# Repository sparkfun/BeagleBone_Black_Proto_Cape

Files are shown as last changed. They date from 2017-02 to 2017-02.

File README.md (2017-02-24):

BeagleBone Black Proto Cape
===========================

[BeagleBone Black Proto Cape
*BeagleBone Black Proto Cape (DEV-12774)*](https://www.sparkfun.com/products/12774)
 
 A prototyping cape designed for the BeagleBone Black. It has blank EEPROM for pin configuration data and
 two red LEDs for debugging. 

Repository Contents
-------------------
* **/Hardware** - All Eagle design files (.brd, .sch, .STL)
* **/Production** - Test bed files and production panel files

Version History
---------------
* [V_1.0.0](https://github.com/sparkfun/BeagleBone_Black_Proto_Cape/tree/V_1.0.0) - Public release
* [V_1.0.1](https://github.com/sparkfun/BeagleBone_Black_Proto_Cape/tree/V_1.0.1) - Updated jumper packages to DFM standard (Increased aperture).

License Information
-------------------
The hardware is released under [Creative Commons ShareAlike 4.0 International](https://creativecommons.org/licenses/by-sa/4.0/).
The code is beerware; if you see me (or any other SparkFun employee) at the local, and you've found our code helpful, please buy us a round!

Distributed as-is; no warranty is given.

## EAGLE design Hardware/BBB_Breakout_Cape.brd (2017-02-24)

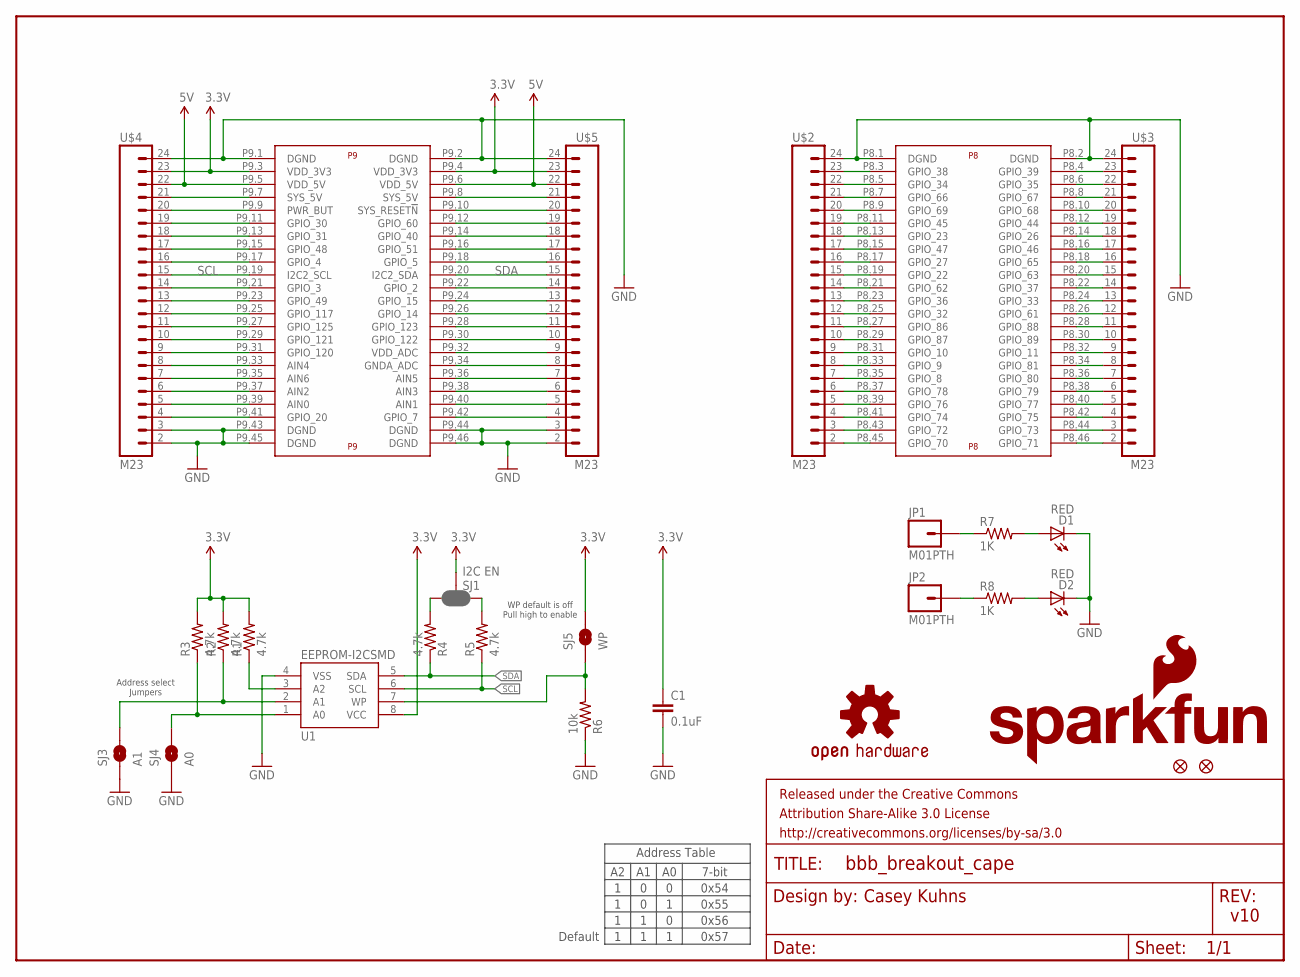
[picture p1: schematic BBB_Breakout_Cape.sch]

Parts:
C1: 0.1uF; 0603-CAP
D1, D2: RED; LED-0603
FID1, FID2: FIDUCIAL1X2; FIDUCIAL-1X2
FRAME1: FRAME-LETTER; CREATIVE_COMMONS
JP1, JP2: M01PTH; 1X01
LOGO2: OSHW-LOGOS; OSHW-LOGO-S
LOGO3: SFE_LOGO_NAME_FLAME.1_INCH; SFE_LOGO_NAME_FLAME_.1
R1, R2, R3, R4, R5: 4.7k; 0603@1
R6: 10k; 0603-RES
R7, R8: 1K; 0603-RES
SJ1: I2C EN; SMT-JUMPER_3_2-NC_PASTE_SILK
SJ3: A1; SMT-JUMPER_2_NO_SILK
SJ4: A0; SMT-JUMPER_2_NO_SILK
SJ5: WP; SMT-JUMPER_2_NO_SILK
U1: EEPROM-I2CSMD; SO08
U$1: BEAGLE_BONE_BLACK_CAPE
U$2, U$3, U$4, U$5: M23; 1X23

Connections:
3.3V: C1.1, R1.2, R2.2, R3.2, SJ1.2, SJ5.2, U1.8 (VCC), U$1.P9.3 (VDD_3V3), U$1.P9.4 (VDD_3V3), U$4.23, U$5.23
5V: U$1.P9.5 (VDD_5V), U$1.P9.6 (VDD_5V), U$4.22, U$5.22
A0: R3.1, SJ4.2, U1.1 (A0)
A1: R2.1, SJ3.2, U1.2 (A1)
GND: C1.2, D1.C, D2.C, R6.1, SJ3.1, SJ4.1, U1.4 (VSS), U$1.P8.1 (DGND), U$1.P8.2 (DGND), U$1.P9.1 (DGND), U$1.P9.2 (DGND), U$1.P9.43 (DGND), U$1.P9.44 (DGND), U$1.P9.45 (DGND), U$1.P9.46 (DGND), U$2.24, U$3.24, U$4.2, U$4.3, U$4.24, U$5.2, U$5.3, U$5.24
unnamed: R6.2, SJ5.1, U1.7 (WP)
unnamed: U$1.P8.45 (GPIO_70), U$2.2
unnamed: D1.A, R7.2
unnamed: U$1.P8.43 (GPIO_72), U$2.3
unnamed: U$1.P8.41 (GPIO_74), U$2.4
unnamed: R1.1, U1.3 (A2)
unnamed: D2.A, R8.2
unnamed: JP1.1, R7.1
unnamed: U$1.P8.39 (GPIO_76), U$2.5
unnamed: R4.2, SJ1.3
unnamed: R5.2, SJ1.1
unnamed: U$1.P8.37 (GPIO_78), U$2.6
unnamed: U$1.P8.35 (GPIO_8), U$2.7
unnamed: U$1.P8.33 (GPIO_9), U$2.8
unnamed: U$1.P8.31 (GPIO_10), U$2.9
unnamed: U$1.P8.29 (GPIO_87), U$2.10
unnamed: U$1.P8.27 (GPIO_86), U$2.11
unnamed: U$1.P8.25 (GPIO_32), U$2.12
unnamed: U$1.P8.23 (GPIO_36), U$2.13
unnamed: U$1.P8.21 (GPIO_62), U$2.14
unnamed: U$1.P8.19 (GPIO_22), U$2.15
unnamed: U$1.P8.17 (GPIO_27), U$2.16
unnamed: U$1.P8.15 (GPIO_47), U$2.17
unnamed: U$1.P8.13 (GPIO_23), U$2.18
unnamed: U$1.P8.11 (GPIO_45), U$2.19
unnamed: U$1.P8.9 (GPIO_69), U$2.20
unnamed: U$1.P8.7 (GPIO_66), U$2.21
unnamed: U$1.P8.5 (GPIO_34), U$2.22
unnamed: U$1.P8.3 (GPIO_38), U$2.23
unnamed: JP2.1, R8.1
unnamed: U$1.P8.46 (GPIO_71), U$3.2
unnamed: U$1.P8.44 (GPIO_73), U$3.3
unnamed: U$1.P8.42 (GPIO_75), U$3.4
unnamed: U$1.P8.40 (GPIO_77), U$3.5
unnamed: U$1.P8.38 (GPIO_79), U$3.6
unnamed: U$1.P8.36 (GPIO_80), U$3.7
unnamed: U$1.P8.34 (GPIO_81), U$3.8
unnamed: U$1.P8.32 (GPIO_11), U$3.9
unnamed: U$1.P8.30 (GPIO_89), U$3.10
unnamed: U$1.P8.28 (GPIO_88), U$3.11
unnamed: U$1.P8.26 (GPIO_61), U$3.12
unnamed: U$1.P8.24 (GPIO_33), U$3.13
unnamed: U$1.P8.22 (GPIO_37), U$3.14
unnamed: U$1.P8.20 (GPIO_63), U$3.15
unnamed: U$1.P8.18 (GPIO_65), U$3.16
unnamed: U$1.P8.16 (GPIO_46), U$3.17
unnamed: U$1.P8.14 (GPIO_26), U$3.18
unnamed: U$1.P8.12 (GPIO_44), U$3.19
unnamed: U$1.P8.10 (GPIO_68), U$3.20
unnamed: U$1.P8.8 (GPIO_67), U$3.21
unnamed: U$1.P8.6 (GPIO_35), U$3.22
unnamed: U$1.P8.4 (GPIO_39), U$3.23
unnamed: U$1.P9.42 (GPIO_7), U$5.4
unnamed: U$1.P9.40 (AIN1), U$5.5
unnamed: U$1.P9.38 (AIN3), U$5.6
unnamed: U$1.P9.36 (AIN5), U$5.7
unnamed: U$1.P9.34 (GNDA_ADC), U$5.8
unnamed: U$1.P9.32 (VDD_ADC), U$5.9
unnamed: U$1.P9.30 (GPIO_122), U$5.10
unnamed: U$1.P9.28 (GPIO_123), U$5.11
unnamed: U$1.P9.26 (GPIO_14), U$5.12
unnamed: U$1.P9.24 (GPIO_15), U$5.13
unnamed: U$1.P9.22 (GPIO_2), U$5.14
unnamed: U$1.P9.18 (GPIO_5), U$5.16
unnamed: U$1.P9.16 (GPIO_51), U$5.17
unnamed: U$1.P9.14 (GPIO_40), U$5.18
unnamed: U$1.P9.12 (GPIO_60), U$5.19
unnamed: U$1.P9.10 (SYS_RESET!N), U$5.20
unnamed: U$1.P9.8 (SYS_5V), U$5.21
unnamed: U$1.P9.41 (GPIO_20), U$4.4
unnamed: U$1.P9.39 (AIN0), U$4.5
unnamed: U$1.P9.37 (AIN2), U$4.6
unnamed: U$1.P9.35 (AIN6), U$4.7
unnamed: U$1.P9.33 (AIN4), U$4.8
unnamed: U$1.P9.31 (GPIO_120), U$4.9
unnamed: U$1.P9.29 (GPIO_121), U$4.10
unnamed: U$1.P9.27 (GPIO_125), U$4.11
unnamed: U$1.P9.25 (GPIO_117), U$4.12
unnamed: U$1.P9.23 (GPIO_49), U$4.13
unnamed: U$1.P9.21 (GPIO_3), U$4.14
unnamed: U$1.P9.17 (GPIO_4), U$4.16
unnamed: U$1.P9.15 (GPIO_48), U$4.17
unnamed: U$1.P9.13 (GPIO_31), U$4.18
unnamed: U$1.P9.11 (GPIO_30), U$4.19
unnamed: U$1.P9.9 (PWR_BUT), U$4.20
unnamed: U$1.P9.7 (SYS_5V), U$4.21
SCL: R5.1, U1.6 (SCL), U$1.P9.19 (I2C2_SCL), U$4.15
SDA: R4.1, U1.5 (SDA), U$1.P9.20 (I2C2_SDA), U$5.15

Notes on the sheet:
Address Table
Default
7-bit
0x54
0x56
0x55
0x57
Casey Kuhns
v10
WP default is off Pull high to enable
Address select Jumpers

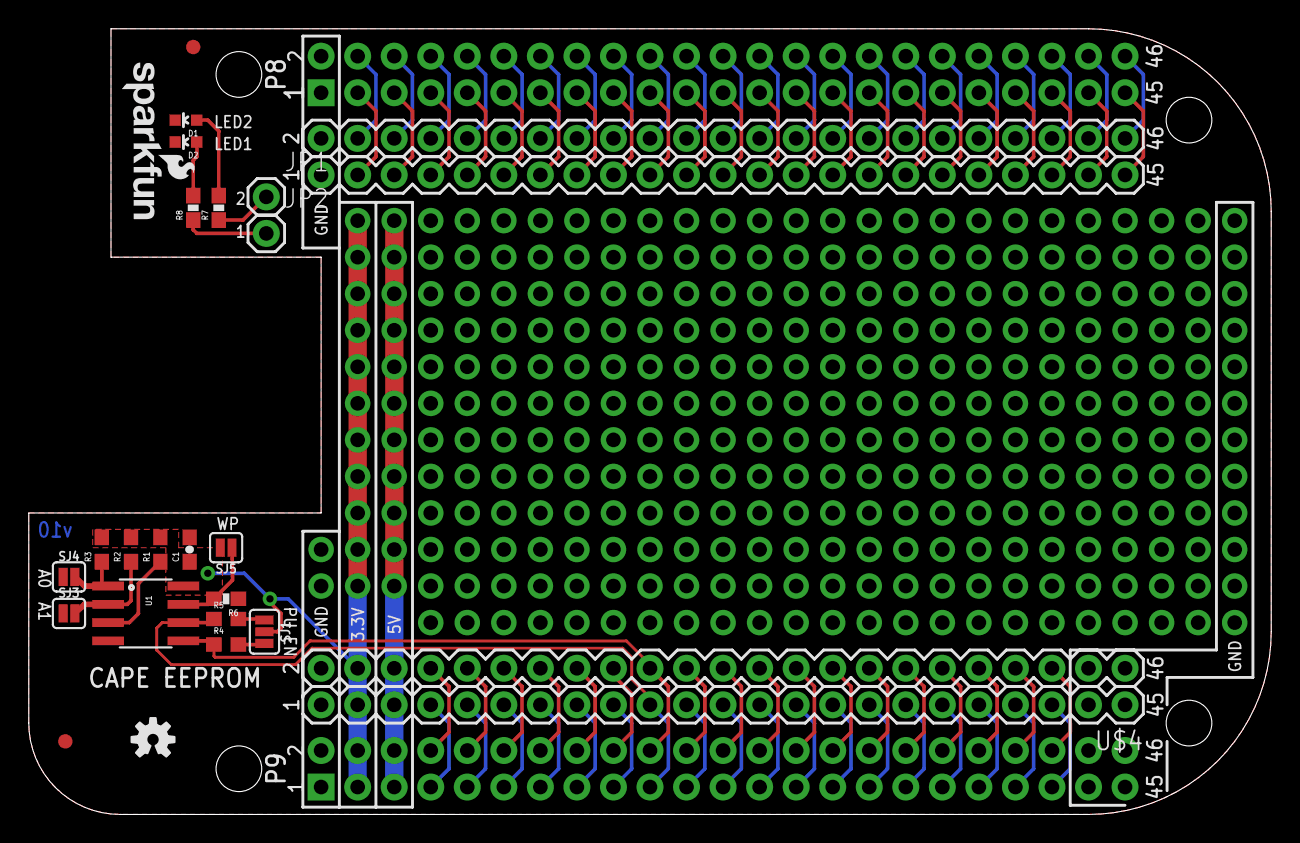
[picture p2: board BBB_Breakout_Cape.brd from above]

Board: 2 copper layers, 86.4 x 54.6 mm, 29 parts (1 on the bottom side), 93 nets.

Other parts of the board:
U$6: SFE_LOGO_NAME_FLAME_.1

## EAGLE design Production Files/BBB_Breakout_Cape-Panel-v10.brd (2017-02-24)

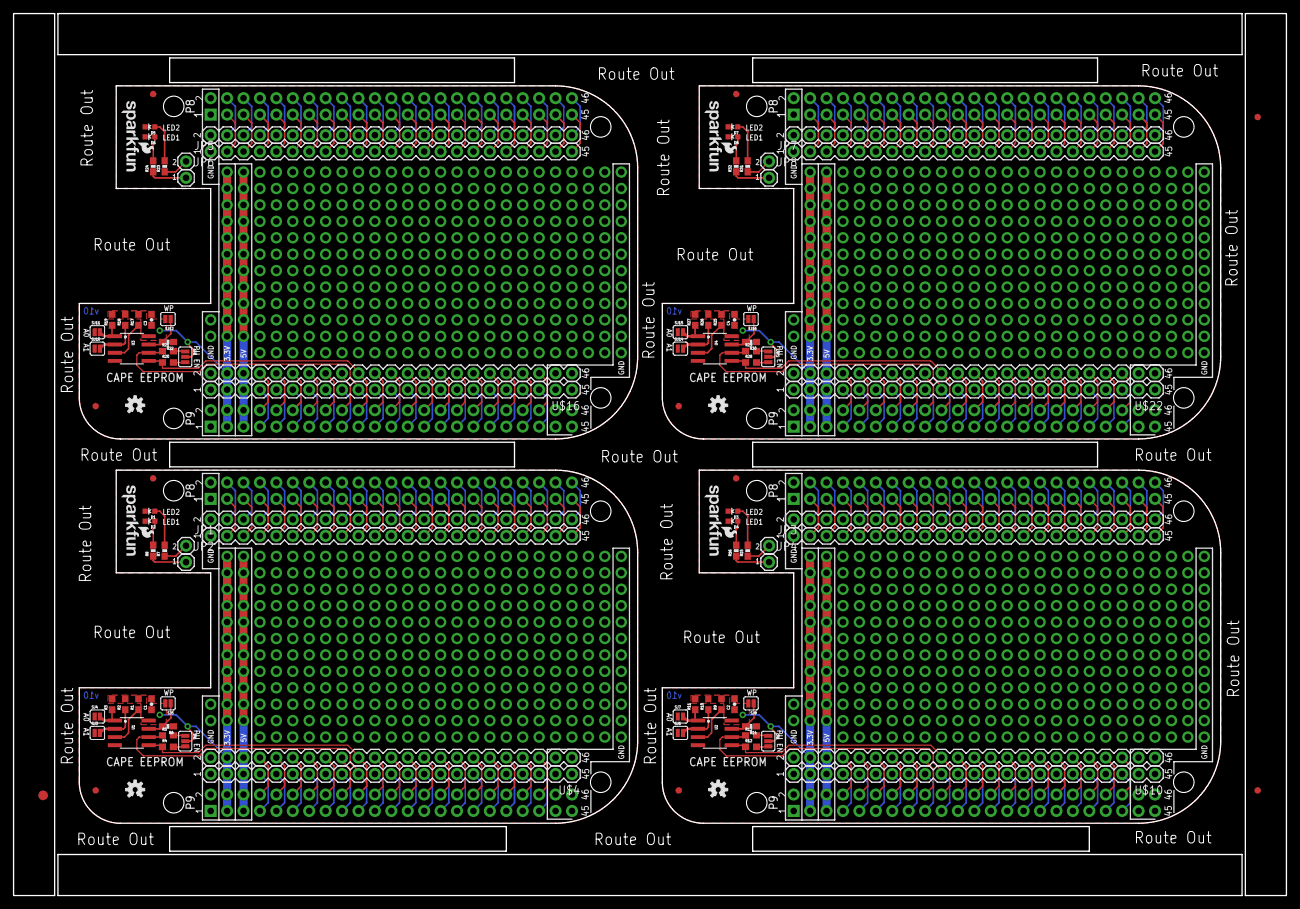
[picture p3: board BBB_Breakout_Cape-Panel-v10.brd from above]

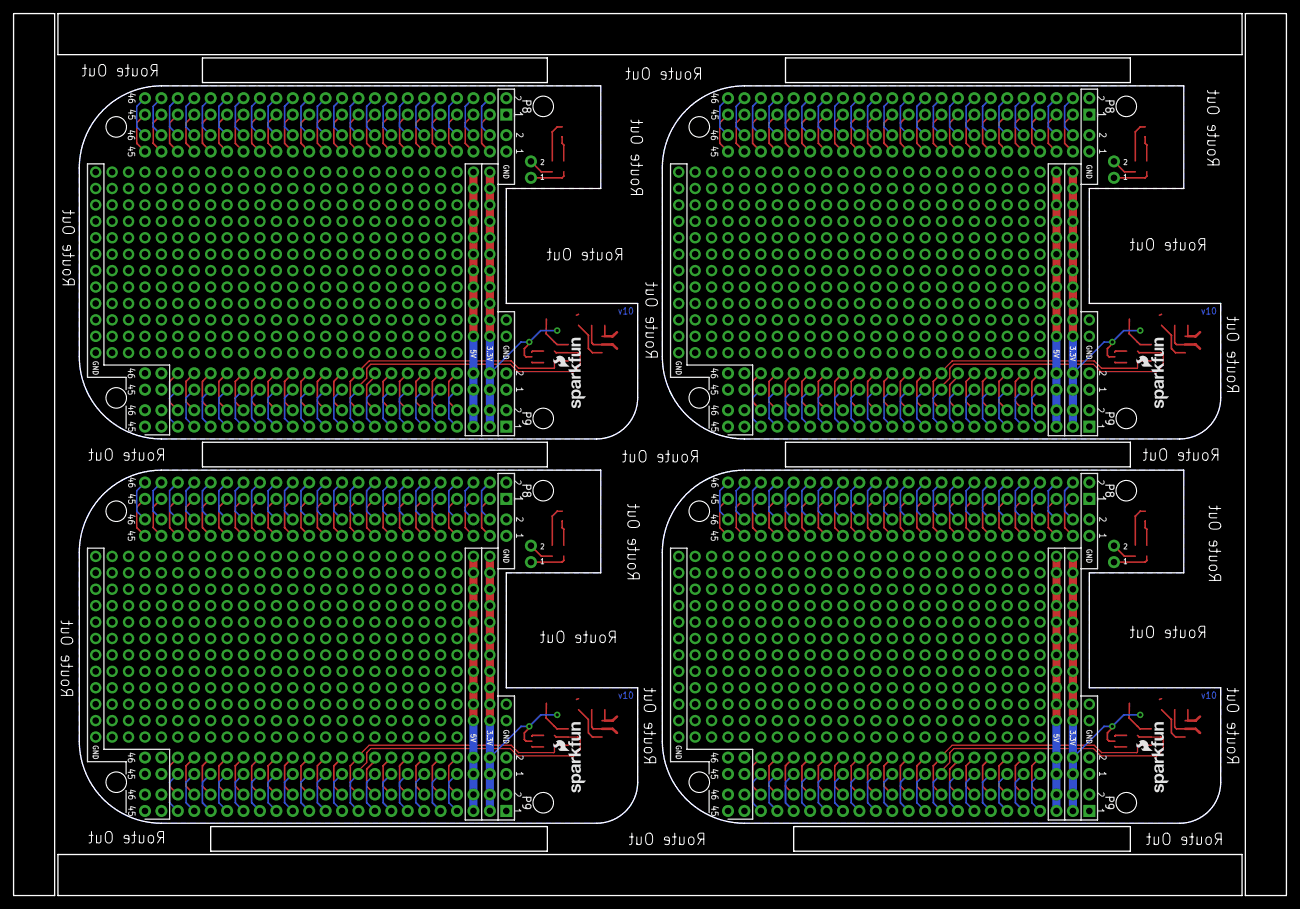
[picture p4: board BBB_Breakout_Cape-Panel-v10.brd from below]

Board: 2 copper layers, 196.8 x 136.4 mm, 115 parts (4 on the bottom side), 372 nets.

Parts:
C1, C2, C3, C4: 0.1uF; 0603-CAP
D1, D2, D3, D4, D5, D6, D7, D8: RED; LED-0603
E$1: FIDUCIAL-1.5X3
E$3, E$4: FIDUCIAL-1X2
FID1, FID2, FID3, FID4, FID5, FID6, FID7, FID8: FIDUCIAL1X2; FIDUCIAL-1X2
JP1, JP2, JP3, JP4, JP5, JP6, JP7, JP8: M01PTH; 1X01
LOGO1, LOGO3, LOGO5, LOGO7: SFE_LOGO_NAME_FLAME.1_INCH; SFE_LOGO_NAME_FLAME_.1
LOGO2, LOGO4, LOGO6, LOGO8: OSHW-LOGOS; OSHW-LOGO-S
R1, R2, R3, R4, R5, R9, R10, R11, R12, R13, R17, R18, R19, R20, R21, R25, R26, R27, R28, R29: 4.7k; 0603
R6, R14, R22, R30: 10k; 0603-RES
R7, R8, R15, R16, R23, R24, R31, R32: 1K; 0603-RES
SJ1, SJ2, SJ9, SJ13: I2C EN; SMT-JUMPER_3_2-NC_PASTE_SILK
SJ3, SJ6, SJ10, SJ14: A1; SMT-JUMPER_2_NO_SILK
SJ4, SJ7, SJ11, SJ15: A0; SMT-JUMPER_2_NO_SILK
SJ5, SJ8, SJ12, SJ16: WP; SMT-JUMPER_2_NO_SILK
U1, U2, U3, U4: EEPROM-I2CSMD; SO08
U$1, U$7, U$13, U$19: BEAGLE_BONE_BLACK_CAPE
U$2, U$3, U$4, U$5, U$8, U$9, U$10, U$11, U$14, U$15, U$16, U$17, U$20, U$21, U$22, U$23: M23; 1X23
U$6, U$12, U$18, U$24: SFE_LOGO_NAME_FLAME_.1

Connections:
3.3V: C1.1, R1.2, R2.2, R3.2, SJ1.2, SJ5.2, U1.8, U$1.P9.3, U$1.P9.4, U$4.23, U$5.23
3.3V1: C2.1, R9.2, R10.2, R11.2, SJ2.2, SJ8.2, U2.8, U$7.P9.3, U$7.P9.4, U$10.23, U$11.23
3.3V2: C3.1, R17.2, R18.2, R19.2, SJ9.2, SJ12.2, U3.8, U$13.P9.3, U$13.P9.4, U$16.23, U$17.23
3.3V3: C4.1, R25.2, R26.2, R27.2, SJ13.2, SJ16.2, U4.8, U$19.P9.3, U$19.P9.4, U$22.23, U$23.23
5V: U$1.P9.5, U$1.P9.6, U$4.22, U$5.22
5V1: U$7.P9.5, U$7.P9.6, U$10.22, U$11.22
5V2: U$13.P9.5, U$13.P9.6, U$16.22, U$17.22
5V3: U$19.P9.5, U$19.P9.6, U$22.22, U$23.22
A0: R3.1, SJ4.2, U1.1
A1: R2.1, SJ3.2, U1.2
A2: R10.1, SJ6.2, U2.2
A3: R11.1, SJ7.2, U2.1
A4: R18.1, SJ10.2, U3.2
A5: R19.1, SJ11.2, U3.1
A6: R26.1, SJ14.2, U4.2
A7: R27.1, SJ15.2, U4.1
GND: C1.2, D1.C, D2.C, R6.1, SJ3.1, SJ4.1, U1.4, U$1.P8.1, U$1.P8.2, U$1.P9.1, U$1.P9.2, U$1.P9.43, U$1.P9.44, U$1.P9.45, U$1.P9.46, U$2.24, U$3.24, U$4.2, U$4.3, U$4.24, U$5.2, U$5.3, U$5.24
GND1: C2.2, D3.C, D4.C, R14.1, SJ6.1, SJ7.1, U2.4, U$7.P8.1, U$7.P8.2, U$7.P9.1, U$7.P9.2, U$7.P9.43, U$7.P9.44, U$7.P9.45, U$7.P9.46, U$8.24, U$9.24, U$10.2, U$10.3, U$10.24, U$11.2, U$11.3, U$11.24
GND2: C3.2, D5.C, D6.C, R22.1, SJ10.1, SJ11.1, U3.4, U$13.P8.1, U$13.P8.2, U$13.P9.1, U$13.P9.2, U$13.P9.43, U$13.P9.44, U$13.P9.45, U$13.P9.46, U$14.24, U$15.24, U$16.2, U$16.3, U$16.24, U$17.2, U$17.3, U$17.24
GND3: C4.2, D7.C, D8.C, R30.1, SJ14.1, SJ15.1, U4.4, U$19.P8.1, U$19.P8.2, U$19.P9.1, U$19.P9.2, U$19.P9.43, U$19.P9.44, U$19.P9.45, U$19.P9.46, U$20.24, U$21.24, U$22.2, U$22.3, U$22.24, U$23.2, U$23.3, U$23.24
unnamed: R6.2, SJ5.1, U1.7
unnamed: U$1.P8.45, U$2.2
unnamed: D1.A, R7.2
unnamed: U$1.P8.43, U$2.3
unnamed: U$1.P8.41, U$2.4
unnamed: R1.1, U1.3
unnamed: D2.A, R8.2
unnamed: JP1.1, R7.1
unnamed: U$1.P8.39, U$2.5
unnamed: R4.2, SJ1.3
unnamed: R5.2, SJ1.1
unnamed: U$1.P8.37, U$2.6
unnamed: U$1.P8.35, U$2.7
unnamed: U$1.P8.33, U$2.8
unnamed: U$1.P8.31, U$2.9
unnamed: U$1.P8.29, U$2.10
unnamed: U$1.P8.27, U$2.11
unnamed: U$1.P8.25, U$2.12
unnamed: U$1.P8.23, U$2.13
unnamed: U$1.P8.21, U$2.14
unnamed: U$1.P8.19, U$2.15
unnamed: U$1.P8.17, U$2.16
unnamed: U$1.P8.15, U$2.17
unnamed: U$1.P8.13, U$2.18
unnamed: U$1.P8.11, U$2.19
unnamed: U$1.P8.9, U$2.20
unnamed: U$1.P8.7, U$2.21
unnamed: U$1.P8.5, U$2.22
unnamed: U$1.P8.3, U$2.23
unnamed: JP2.1, R8.1
unnamed: U$1.P8.46, U$3.2
unnamed: U$1.P8.44, U$3.3
unnamed: U$1.P8.42, U$3.4
unnamed: U$1.P8.40, U$3.5
unnamed: U$1.P8.38, U$3.6
unnamed: U$1.P8.36, U$3.7
unnamed: U$1.P8.34, U$3.8
unnamed: U$1.P8.32, U$3.9
unnamed: U$1.P8.30, U$3.10
unnamed: U$1.P8.28, U$3.11
unnamed: U$1.P8.26, U$3.12
unnamed: U$1.P8.24, U$3.13
unnamed: U$1.P8.22, U$3.14
unnamed: U$1.P8.20, U$3.15
unnamed: U$1.P8.18, U$3.16
unnamed: U$1.P8.16, U$3.17
unnamed: U$1.P8.14, U$3.18
unnamed: U$1.P8.12, U$3.19
unnamed: U$1.P8.10, U$3.20
unnamed: U$1.P8.8, U$3.21
unnamed: U$1.P8.6, U$3.22
unnamed: U$1.P8.4, U$3.23
unnamed: R9.1, U2.3
unnamed: R12.2, SJ2.3
unnamed: R13.2, SJ2.1
unnamed: U$1.P9.42, U$5.4
unnamed: U$1.P9.40, U$5.5
unnamed: U$1.P9.38, U$5.6
unnamed: U$1.P9.36, U$5.7
unnamed: U$1.P9.34, U$5.8
unnamed: U$1.P9.32, U$5.9
unnamed: U$1.P9.30, U$5.10
unnamed: U$1.P9.28, U$5.11
unnamed: U$1.P9.26, U$5.12
unnamed: U$1.P9.24, U$5.13
unnamed: U$1.P9.22, U$5.14
unnamed: U$7.P8.45, U$8.2
unnamed: U$1.P9.18, U$5.16
unnamed: U$1.P9.16, U$5.17
unnamed: U$1.P9.14, U$5.18
unnamed: U$1.P9.12, U$5.19
unnamed: U$1.P9.10, U$5.20
unnamed: U$1.P9.8, U$5.21
unnamed: U$7.P8.43, U$8.3
unnamed: U$7.P8.41, U$8.4
unnamed: U$7.P8.39, U$8.5
unnamed: U$7.P8.37, U$8.6
unnamed: U$7.P8.35, U$8.7
unnamed: U$1.P9.41, U$4.4
unnamed: U$1.P9.39, U$4.5
unnamed: U$1.P9.37, U$4.6
unnamed: U$1.P9.35, U$4.7
unnamed: U$1.P9.33, U$4.8
unnamed: U$1.P9.31, U$4.9
unnamed: U$1.P9.29, U$4.10
unnamed: U$1.P9.27, U$4.11
unnamed: U$1.P9.25, U$4.12
unnamed: U$1.P9.23, U$4.13
unnamed: U$1.P9.21, U$4.14
unnamed: U$7.P8.33, U$8.8
unnamed: U$1.P9.17, U$4.16
unnamed: U$1.P9.15, U$4.17
unnamed: U$1.P9.13, U$4.18
unnamed: U$1.P9.11, U$4.19
unnamed: U$1.P9.9, U$4.20
unnamed: U$1.P9.7, U$4.21
unnamed: U$7.P8.31, U$8.9
unnamed: U$7.P8.29, U$8.10
unnamed: U$7.P8.27, U$8.11
unnamed: U$7.P8.25, U$8.12
unnamed: U$7.P8.23, U$8.13
unnamed: U$7.P8.21, U$8.14
unnamed: U$7.P8.19, U$8.15
unnamed: U$7.P8.17, U$8.16
unnamed: U$7.P8.15, U$8.17
unnamed: U$7.P8.13, U$8.18
unnamed: U$7.P8.11, U$8.19
unnamed: U$7.P8.9, U$8.20
unnamed: U$7.P8.7, U$8.21
unnamed: U$7.P8.5, U$8.22
unnamed: U$7.P8.3, U$8.23
unnamed: U$7.P8.46, U$9.2
unnamed: U$7.P8.44, U$9.3
unnamed: U$7.P8.42, U$9.4
unnamed: U$7.P8.40, U$9.5
unnamed: U$7.P8.38, U$9.6
unnamed: U$7.P8.36, U$9.7
unnamed: U$7.P8.34, U$9.8
unnamed: U$7.P8.32, U$9.9
unnamed: U$7.P8.30, U$9.10
unnamed: U$7.P8.28, U$9.11
unnamed: U$7.P8.26, U$9.12
unnamed: U$7.P8.24, U$9.13
unnamed: U$7.P8.22, U$9.14
unnamed: U$7.P8.20, U$9.15
unnamed: U$7.P8.18, U$9.16
unnamed: U$7.P8.16, U$9.17
unnamed: U$7.P8.14, U$9.18
unnamed: U$7.P8.12, U$9.19
unnamed: U$7.P8.10, U$9.20
unnamed: U$7.P8.8, U$9.21
unnamed: U$7.P8.6, U$9.22
unnamed: U$7.P8.4, U$9.23
unnamed: U$7.P9.42, U$11.4
unnamed: U$7.P9.40, U$11.5
unnamed: U$7.P9.38, U$11.6
unnamed: U$7.P9.36, U$11.7
unnamed: U$7.P9.34, U$11.8
unnamed: U$7.P9.32, U$11.9
unnamed: U$7.P9.30, U$11.10
unnamed: U$7.P9.28, U$11.11
unnamed: U$7.P9.26, U$11.12
unnamed: U$7.P9.24, U$11.13
unnamed: U$7.P9.22, U$11.14
unnamed: U$7.P9.18, U$11.16
unnamed: U$7.P9.16, U$11.17
unnamed: U$7.P9.14, U$11.18
unnamed: U$7.P9.12, U$11.19
unnamed: U$7.P9.10, U$11.20
unnamed: U$7.P9.8, U$11.21
unnamed: U$7.P9.41, U$10.4
unnamed: U$7.P9.39, U$10.5
unnamed: U$7.P9.37, U$10.6
unnamed: U$7.P9.35, U$10.7
unnamed: U$7.P9.33, U$10.8
unnamed: U$7.P9.31, U$10.9
unnamed: U$7.P9.29, U$10.10
unnamed: U$7.P9.27, U$10.11
unnamed: U$7.P9.25, U$10.12
unnamed: U$7.P9.23, U$10.13
unnamed: U$7.P9.21, U$10.14
unnamed: U$7.P9.17, U$10.16
unnamed: U$7.P9.15, U$10.17
unnamed: U$7.P9.13, U$10.18
unnamed: U$7.P9.11, U$10.19
unnamed: U$7.P9.9, U$10.20
unnamed: U$7.P9.7, U$10.21
unnamed: R14.2, SJ8.1, U2.7
unnamed: D3.A, R15.2
unnamed: D4.A, R16.2
unnamed: JP3.1, R15.1
unnamed: JP4.1, R16.1
unnamed: R17.1, U3.3
unnamed: R20.2, SJ9.3
unnamed: R21.2, SJ9.1
unnamed: U$13.P8.45, U$14.2
unnamed: U$13.P8.43, U$14.3
unnamed: U$13.P8.41, U$14.4
unnamed: U$13.P8.39, U$14.5
unnamed: U$13.P8.37, U$14.6
unnamed: U$13.P8.35, U$14.7
unnamed: U$13.P8.33, U$14.8
unnamed: U$13.P8.31, U$14.9
unnamed: U$13.P8.29, U$14.10
unnamed: U$13.P8.27, U$14.11
unnamed: U$13.P8.25, U$14.12
unnamed: U$13.P8.23, U$14.13
unnamed: U$13.P8.21, U$14.14
unnamed: U$13.P8.19, U$14.15
unnamed: U$13.P8.17, U$14.16
unnamed: U$13.P8.15, U$14.17
unnamed: U$13.P8.13, U$14.18
unnamed: U$13.P8.11, U$14.19
unnamed: U$13.P8.9, U$14.20
unnamed: U$13.P8.7, U$14.21
unnamed: U$13.P8.5, U$14.22
unnamed: U$13.P8.3, U$14.23
unnamed: U$13.P8.46, U$15.2
unnamed: U$13.P8.44, U$15.3
unnamed: U$13.P8.42, U$15.4
unnamed: U$13.P8.40, U$15.5
unnamed: U$13.P8.38, U$15.6
unnamed: U$13.P8.36, U$15.7
unnamed: U$13.P8.34, U$15.8
unnamed: U$13.P8.32, U$15.9
unnamed: U$13.P8.30, U$15.10
unnamed: U$13.P8.28, U$15.11
unnamed: U$13.P8.26, U$15.12
unnamed: U$13.P8.24, U$15.13
unnamed: U$13.P8.22, U$15.14
unnamed: U$13.P8.20, U$15.15
unnamed: U$13.P8.18, U$15.16
unnamed: U$13.P8.16, U$15.17
unnamed: U$13.P8.14, U$15.18
unnamed: U$13.P8.12, U$15.19
unnamed: U$13.P8.10, U$15.20
unnamed: U$13.P8.8, U$15.21
unnamed: U$13.P8.6, U$15.22
unnamed: U$13.P8.4, U$15.23
unnamed: U$13.P9.42, U$17.4
unnamed: U$13.P9.40, U$17.5
unnamed: U$13.P9.38, U$17.6
unnamed: U$13.P9.36, U$17.7
unnamed: U$13.P9.34, U$17.8
unnamed: U$13.P9.32, U$17.9
unnamed: U$13.P9.30, U$17.10
unnamed: U$13.P9.28, U$17.11
unnamed: U$13.P9.26, U$17.12
unnamed: U$13.P9.24, U$17.13
unnamed: U$13.P9.22, U$17.14
unnamed: U$13.P9.18, U$17.16
unnamed: U$13.P9.16, U$17.17
unnamed: U$13.P9.14, U$17.18
unnamed: U$13.P9.12, U$17.19
unnamed: U$13.P9.10, U$17.20
unnamed: U$13.P9.8, U$17.21
unnamed: U$13.P9.41, U$16.4
unnamed: U$13.P9.39, U$16.5
unnamed: U$13.P9.37, U$16.6
unnamed: U$13.P9.35, U$16.7
unnamed: U$13.P9.33, U$16.8
unnamed: U$13.P9.31, U$16.9
unnamed: U$13.P9.29, U$16.10
unnamed: U$13.P9.27, U$16.11
unnamed: U$13.P9.25, U$16.12
unnamed: U$13.P9.23, U$16.13
unnamed: U$13.P9.21, U$16.14
unnamed: U$13.P9.17, U$16.16
unnamed: U$13.P9.15, U$16.17
unnamed: U$13.P9.13, U$16.18
unnamed: U$13.P9.11, U$16.19
unnamed: U$13.P9.9, U$16.20
unnamed: U$13.P9.7, U$16.21
unnamed: R22.2, SJ12.1, U3.7
unnamed: D5.A, R23.2
unnamed: D6.A, R24.2
unnamed: JP5.1, R23.1
unnamed: JP6.1, R24.1
unnamed: R25.1, U4.3
unnamed: R28.2, SJ13.3
unnamed: R29.2, SJ13.1
unnamed: U$19.P8.45, U$20.2
unnamed: U$19.P8.43, U$20.3
unnamed: U$19.P8.41, U$20.4
unnamed: U$19.P8.39, U$20.5
unnamed: U$19.P8.37, U$20.6
unnamed: U$19.P8.35, U$20.7
unnamed: U$19.P8.33, U$20.8
unnamed: U$19.P8.31, U$20.9
unnamed: U$19.P8.29, U$20.10
unnamed: U$19.P8.27, U$20.11
unnamed: U$19.P8.25, U$20.12
unnamed: U$19.P8.23, U$20.13
unnamed: U$19.P8.21, U$20.14
unnamed: U$19.P8.19, U$20.15
unnamed: U$19.P8.17, U$20.16
unnamed: U$19.P8.15, U$20.17
unnamed: U$19.P8.13, U$20.18
unnamed: U$19.P8.11, U$20.19
unnamed: U$19.P8.9, U$20.20
unnamed: U$19.P8.7, U$20.21
unnamed: U$19.P8.5, U$20.22
unnamed: U$19.P8.3, U$20.23
unnamed: U$19.P8.46, U$21.2
unnamed: U$19.P8.44, U$21.3
unnamed: U$19.P8.42, U$21.4
unnamed: U$19.P8.40, U$21.5
unnamed: U$19.P8.38, U$21.6
unnamed: U$19.P8.36, U$21.7
unnamed: U$19.P8.34, U$21.8
unnamed: U$19.P8.32, U$21.9
unnamed: U$19.P8.30, U$21.10
unnamed: U$19.P8.28, U$21.11
unnamed: U$19.P8.26, U$21.12
unnamed: U$19.P8.24, U$21.13
unnamed: U$19.P8.22, U$21.14
unnamed: U$19.P8.20, U$21.15
unnamed: U$19.P8.18, U$21.16
unnamed: U$19.P8.16, U$21.17
unnamed: U$19.P8.14, U$21.18
unnamed: U$19.P8.12, U$21.19
unnamed: U$19.P8.10, U$21.20
unnamed: U$19.P8.8, U$21.21
unnamed: U$19.P8.6, U$21.22
unnamed: U$19.P8.4, U$21.23
unnamed: U$19.P9.42, U$23.4
unnamed: U$19.P9.40, U$23.5
unnamed: U$19.P9.38, U$23.6
unnamed: U$19.P9.36, U$23.7
unnamed: U$19.P9.34, U$23.8
unnamed: U$19.P9.32, U$23.9
unnamed: U$19.P9.30, U$23.10
unnamed: U$19.P9.28, U$23.11
unnamed: U$19.P9.26, U$23.12
unnamed: U$19.P9.24, U$23.13
unnamed: U$19.P9.22, U$23.14
unnamed: U$19.P9.18, U$23.16
unnamed: U$19.P9.16, U$23.17
unnamed: U$19.P9.14, U$23.18
unnamed: U$19.P9.12, U$23.19
unnamed: U$19.P9.10, U$23.20
unnamed: U$19.P9.8, U$23.21
unnamed: U$19.P9.41, U$22.4
unnamed: U$19.P9.39, U$22.5
unnamed: U$19.P9.37, U$22.6
unnamed: U$19.P9.35, U$22.7
unnamed: U$19.P9.33, U$22.8
unnamed: U$19.P9.31, U$22.9
unnamed: U$19.P9.29, U$22.10
unnamed: U$19.P9.27, U$22.11
unnamed: U$19.P9.25, U$22.12
unnamed: U$19.P9.23, U$22.13
unnamed: U$19.P9.21, U$22.14
unnamed: U$19.P9.17, U$22.16
unnamed: U$19.P9.15, U$22.17
unnamed: U$19.P9.13, U$22.18
unnamed: U$19.P9.11, U$22.19
unnamed: U$19.P9.9, U$22.20
unnamed: U$19.P9.7, U$22.21
unnamed: R30.2, SJ16.1, U4.7
unnamed: D7.A, R31.2
unnamed: D8.A, R32.2
unnamed: JP7.1, R31.1
unnamed: JP8.1, R32.1
SCL: R5.1, U1.6, U$1.P9.19, U$4.15
SCL1: R13.1, U2.6, U$7.P9.19, U$10.15
SCL2: R21.1, U3.6, U$13.P9.19, U$16.15
SCL3: R29.1, U4.6, U$19.P9.19, U$22.15
SDA: R4.1, U1.5, U$1.P9.20, U$5.15
SDA1: R12.1, U2.5, U$7.P9.20, U$11.15
SDA2: R20.1, U3.5, U$13.P9.20, U$17.15
SDA3: R28.1, U4.5, U$19.P9.20, U$23.15

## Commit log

2014-01-07 Initial Board commit
    [BBB_Breakout_Cape.0.brd, BBB_Breakout_Cape.0.sch, BBB_Breakout_Cape.brd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]
2014-02-13 board ready for review
    [BBB_Breakout_Cape.0.brd, BBB_Breakout_Cape.0.sch, BBB_Breakout_Cape.brd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]
2014-02-14 Updated labels and corrected silk on bottom layer
    [BBB_Breakout_Cape.brd, BBB_Breakout_Cape.sch]
2014-02-20 added labels and corrected WP jumper to eliminate possible short.
    [BBB_Breakout_Cape.brd, BBB_Breakout_Cape.sch]
2014-03-04 Changed I2C EN to PU EN
    [BBB_Breakout_Cape.brd]
2014-03-24 added LEDS
    [BBB_Breakout_Cape.brd, BBB_Breakout_Cape.sch]
2014-03-24 added more labels and fixed drill hole
    [BBB_Breakout_Cape.brd, BBB_Breakout_Cape.sch]
2014-03-24 added version number
    [BBB_Breakout_Cape.brd, BBB_Breakout_Cape.sch]
2014-03-25 added local fiducials
    [BBB_Breakout_Cape.brd, BBB_Breakout_Cape.sch]
2014-03-25 Created Panel v10
    [BBB_Breakout_Cape-Panel-v10.brd]
2017-02-24 Updated juper packages on design and panel. This only effects tcream layer.
    [BBB_Breakout_Cape-Panel-v10.brd, BBB_Breakout_Cape.brd, BBB_Breakout_Cape.sch]

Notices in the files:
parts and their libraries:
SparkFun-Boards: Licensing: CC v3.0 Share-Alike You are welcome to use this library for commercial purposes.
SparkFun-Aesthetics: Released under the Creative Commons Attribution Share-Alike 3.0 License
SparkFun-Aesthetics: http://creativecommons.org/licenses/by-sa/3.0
